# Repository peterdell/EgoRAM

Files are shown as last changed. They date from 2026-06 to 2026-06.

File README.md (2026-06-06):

# EgoRAM

The Atari 8-bit RAM cartridge with an own ego and opinion what should be in the RAM.

$D500-$D5FF
===========

| Address | Name | Descriptio Read | Write |
|---------+------+------------|
| $D500   |      | 'E'        |
| $D501   |      | 'R'        |
| $D502   |      | 'A'        |
| $D503   |      | 'M'        |
| $D504   |      | $YY        |
| $D505   |      | $YY        |
| $D506   |      | $MM        |
| $D507   |      | $DD        |

| $D508   |  ECTL  | $00=ready, $01=busy, $8x=error  | $00=reset,$01=begin command |
| $D509   |  EDAT  | Data, increments address        | Data to write, increments address |
| $dD0a   |  ERET  | n/a                             | Strobe, run command |

| Command | Name     | Arguments | Description 
| G       | Graphics | mode: byte (8,9,15), address: word ($8000...$bffff), width: byte (bytes 32,40,48), height: byte (lines 1..255) | width*height<$2000
| SD      | Shape Define | shapeNumber: word ($0001-$ffff), bpp: ($01, $02, $04), width: word (pixels 1..256), height: word (pixels 1..256), format: byte ($01=raw), paletteSize: word, paletteMap: array[paletteSize], maskIndex: byte (0..paletteSize), data: array[0...dataSize-1] | dataSize =

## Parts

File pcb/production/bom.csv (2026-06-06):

Designator | Footprint | Quantity | Value | LCSC Part #
J1 | PinHeader_1x04_P2.54mm_Horizontal | 1 | Conn_01x04_Pin
J7, J8 | PinSocket_1x20_P2.54mm_Vertical | 2 | Conn_01x20
SW1 | SW_PUSH_6mm_H8mm | 1 | SW_Push
U1, U3, U4, U5 | DIP-20_W7.62mm_Socket_LongPads | 4 | 74LS245
U2 | Atari8Cartridge MountHoles (taller) | 1 | Atari8Cartridge
U6 | DIP-14_W7.62mm_LongPads | 1 | 74LS08

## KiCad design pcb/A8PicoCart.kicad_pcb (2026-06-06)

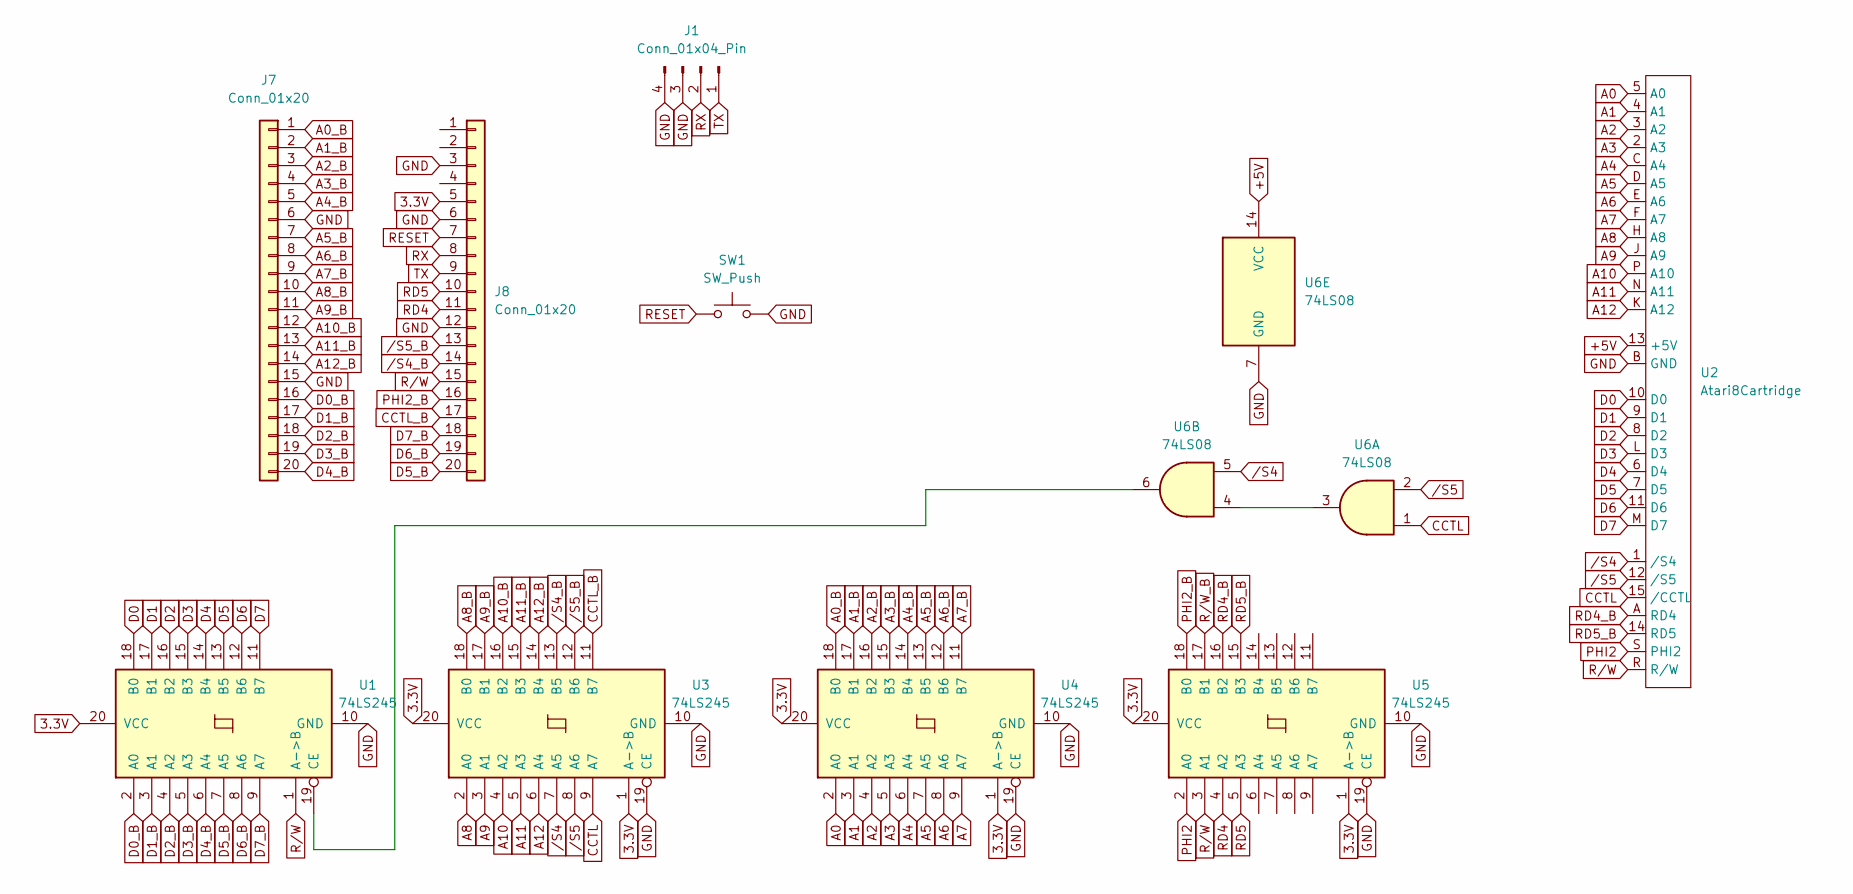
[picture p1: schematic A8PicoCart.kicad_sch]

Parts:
J1: Conn_01x04_Pin; PinHeader_1x04_P2.54mm_Horizontal
J7, J8: Conn_01x20; PinSocket_1x20_P2.54mm_Vertical
SW1: SW_Push; SW_PUSH_6mm_H8mm
U1, U3, U4, U5: 74LS245; DIP-20_W7.62mm_Socket_LongPads
U2: Atari8Cartridge; Atari8Cartridge MountHoles (taller)
U6: 74LS08; DIP-14_W7.62mm_LongPads

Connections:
3.3V: J8.5, U1.20 (VCC), U3.1 (A->B), U3.20 (VCC), U4.1 (A->B), U4.20 (VCC), U5.1 (A->B), U5.20 (VCC)
+5V: U2.13 (+5V), U6.14 (VCC)
A0: U2.5 (A0), U4.2 (A0)
A0_B: J7.1, U4.18 (B0)
A1: U2.4 (A1), U4.3 (A1)
A1_B: J7.2, U4.17 (B1)
A2: U2.3 (A2), U4.4 (A2)
A2_B: J7.3, U4.16 (B2)
A3: U2.2 (A3), U4.5 (A3)
A3_B: J7.4, U4.15 (B3)
A4: U2.C (A4), U4.6 (A4)
A4_B: J7.5, U4.14 (B4)
A5: U2.D (A5), U4.7 (A5)
A5_B: J7.7, U4.13 (B5)
A6: U2.E (A6), U4.8 (A6)
A6_B: J7.8, U4.12 (B6)
A7: U2.F (A7), U4.9 (A7)
A7_B: J7.9, U4.11 (B7)
A8: U2.H (A8), U3.2 (A0)
A8_B: J7.10, U3.18 (B0)
A9: U2.J (A9), U3.3 (A1)
A9_B: J7.11, U3.17 (B1)
A10: U2.P (A10), U3.4 (A2)
A10_B: J7.12, U3.16 (B2)
A11: U2.N (A11), U3.5 (A3)
A11_B: J7.13, U3.15 (B3)
A12: U2.K (A12), U3.6 (A4)
A12_B: J7.14, U3.14 (B4)
CCTL: U2.15 (/CCTL), U3.9 (A7), U6.1
CCTL_B: J8.17, U3.11 (B7)
D0: U1.18 (B0), U2.10 (D0)
D0_B: J7.16, U1.2 (A0)
D1: U1.17 (B1), U2.9 (D1)
D1_B: J7.17, U1.3 (A1)
D2: U1.16 (B2), U2.8 (D2)
D2_B: J7.18, U1.4 (A2)
D3: U1.15 (B3), U2.L (D3)
D3_B: J7.19, U1.5 (A3)
D4: U1.14 (B4), U2.6 (D4)
D4_B: J7.20, U1.6 (A4)
D5: U1.13 (B5), U2.7 (D5)
D5_B: J8.20, U1.7 (A5)
D6: U1.12 (B6), U2.11 (D6)
D6_B: J8.19, U1.8 (A6)
D7: U1.11 (B7), U2.M (D7)
D7_B: J8.18, U1.9 (A7)
GND: J1.3, J1.4, J7.6, J7.15, J8.3, J8.6, J8.12, SW1.2, U1.10 (GND), U2.B (GND), U3.10 (GND), U3.19 (CE), U4.10 (GND), U4.19 (CE), U5.10 (GND), U5.19 (CE), U6.7 (GND)
unnamed: U1.19 (CE), U6.6
unnamed: U6.3, U6.4
PHI2: U2.S (PHI2), U5.2 (A0)
PHI2_B: J8.16, U5.18 (B0)
RD4: J8.11, U5.4 (A2)
RD4_B: U2.A (RD4), U5.16 (B2)
RD5: J8.10, U5.5 (A3)
RD5_B: U2.14 (RD5), U5.15 (B3)
RESET: J8.7, SW1.1
RX: J1.2, J8.8
R/W: J8.15, U1.1 (A->B), U2.R (R/W), U5.3 (A1)
R/W_B: U5.17 (B1)
TX: J1.1, J8.9
/S4: U2.1 (/S4), U3.7 (A5), U6.5
/S4_B: J8.14, U3.13 (B5)
/S5: U2.12 (/S5), U3.8 (A6), U6.2
/S5_B: J8.13, U3.12 (B6)

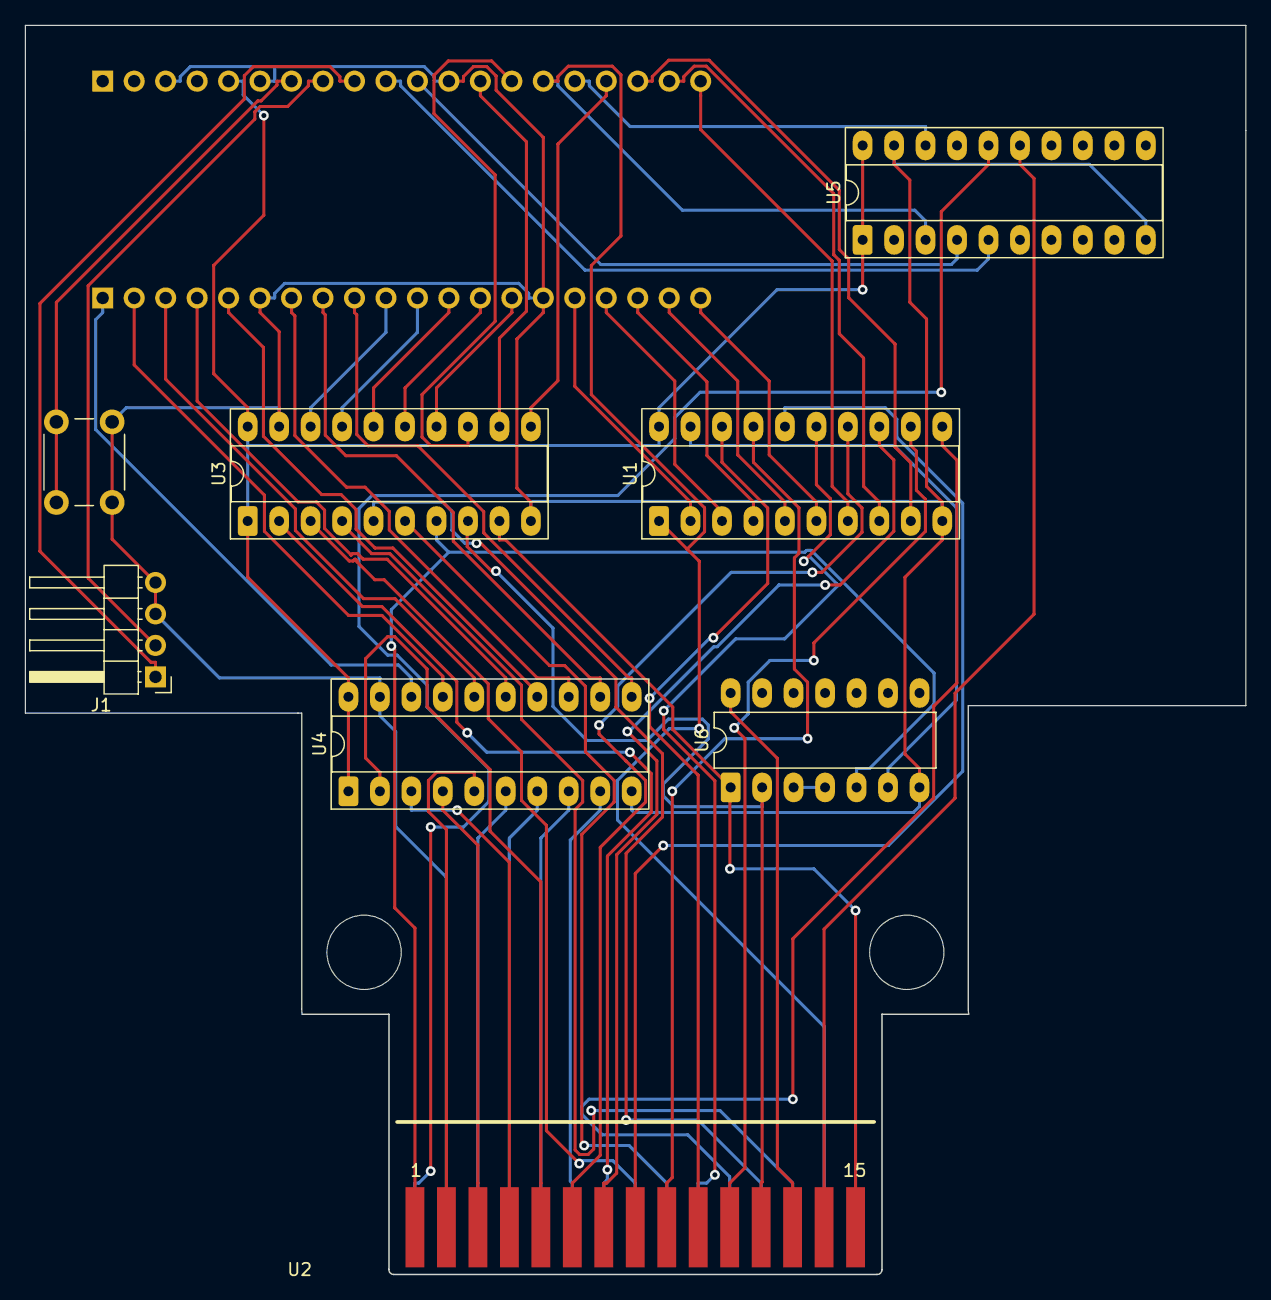
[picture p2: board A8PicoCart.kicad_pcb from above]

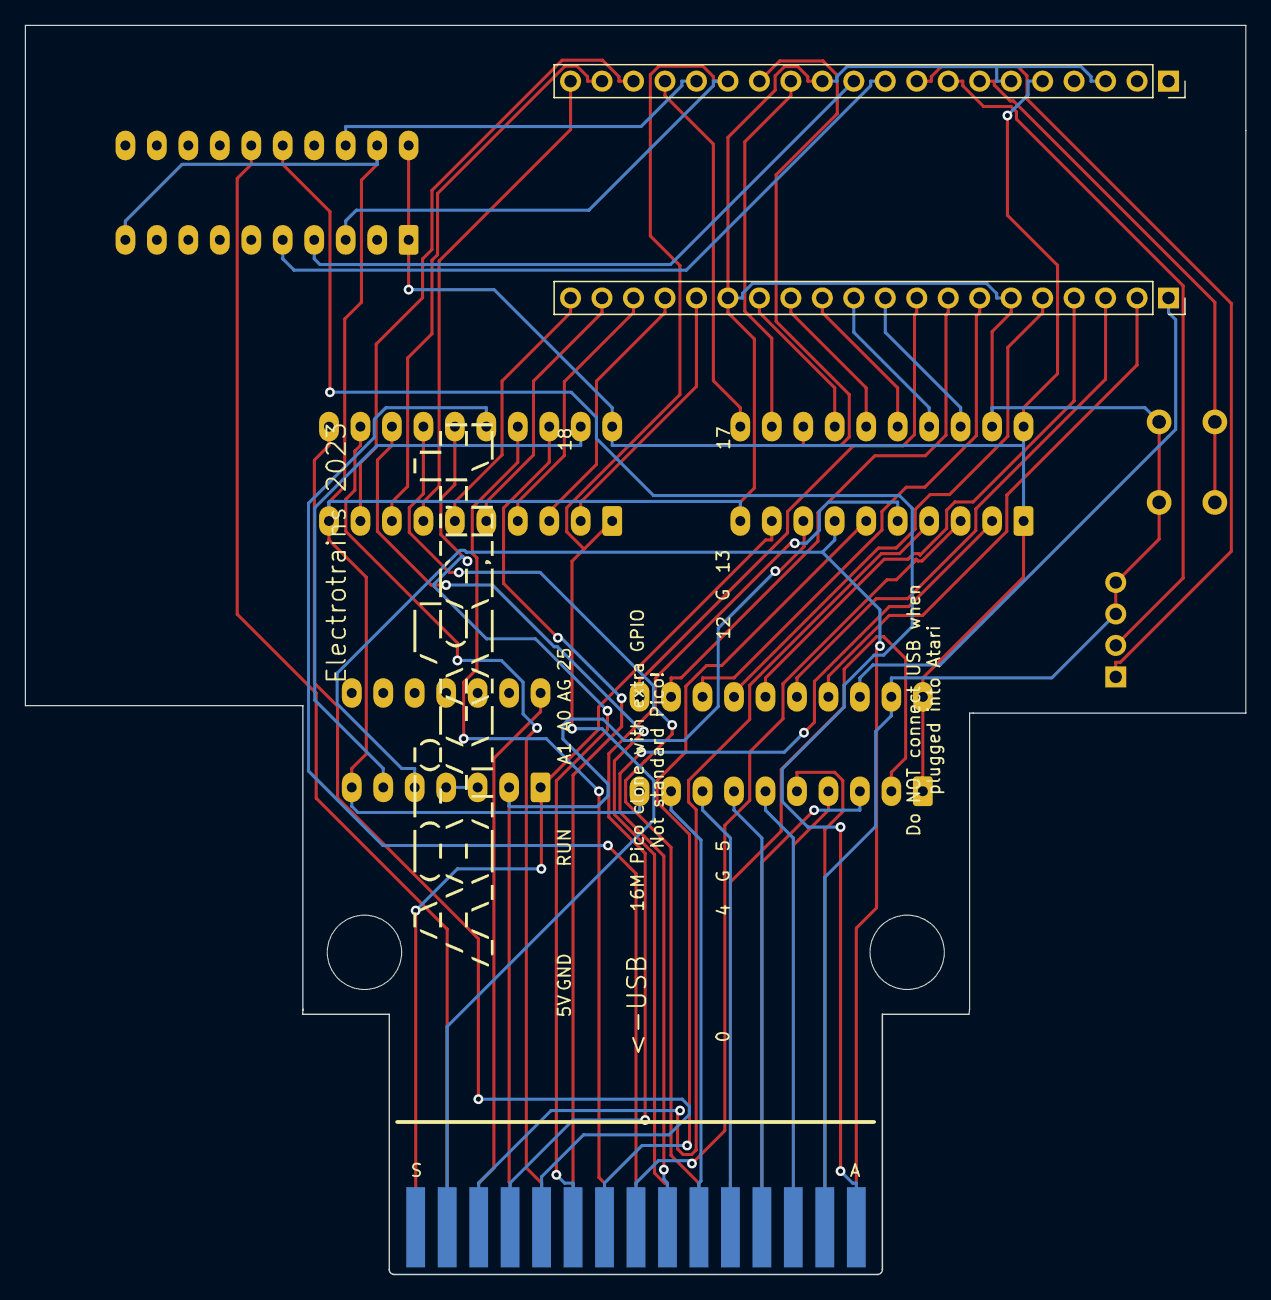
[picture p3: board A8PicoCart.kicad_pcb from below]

Board: 2 copper layers, 98.5 x 100.8 mm, 10 parts (2 on the bottom side), 63 nets.

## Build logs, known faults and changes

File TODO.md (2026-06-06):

- Create Atari test/sample program

- Define D500 Layout
- Implement BUSY Bit

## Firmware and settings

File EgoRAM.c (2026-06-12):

/**
 * Copyright (c) 2020 Raspberry Pi (Trading) Ltd.
 *
 * SPDX-License-Identifier: BSD-3-Clause
 */

/*

A0-12  13
D0-7    8
CCTL    1   gpio 21
PHI2    1   gpio 22
RW      1   gpio 23
S4      1   gpio 24
S5      1   gpio 25
    ------
       26
    ======

#define ALL_GPIO_MASK 0x3FFFFFFF
#define ADDR_GPIO_MASK 0x00001FFF
#define DATA_GPIO_MASK 0x001FE000
#define CCTL_GPIO_MASK 0x00200000 // gpio 21
#define PHI2_GPIO_MASK 0x00400000 // gpio 22
#define RW_GPIO_MASK 0x00800000	  // gpio 23
#define S4_GPIO_MASK 0x01000000	  // gpio 24
#define S5_GPIO_MASK 0x02000000	  // gpio 25
*/

#include <stdio.h>
#include <stdlib.h>
#include <string.h>
#include <stdarg.h>
#include "pico/stdlib.h"
#include "pico/multicore.h"
#include "pico/rand.h"
#include "hardware/pio.h"
#include "hardware/clocks.h"
#include "hardware/pll.h"
#include "hardware/structs/systick.h"
#include "hardware/vreg.h"
#include "hardware/structs/bus_ctrl.h"
#include "hardware/regs/busctrl.h"

#include "vt100_font_8x8.h"
#include "atari_cart.h"
#include "EgoRAM.h"
#include "cvideo.h"

char c;

int dx_array[EGO_MAX_SPRITES];
int dy_array[EGO_MAX_SPRITES];

static char strbuf[80];

static uint8_t *char_font = (uint8_t *)vt100_font_8x8;
static uint32_t mode;

static volatile uint8_t *video_ram;
static volatile uint8_t *cart_d5xx;
static volatile uint32_t ticks;
static bool uart_init_once;

static uint8_t ego_cmd;
static uint32_t ego_state;
static uint32_t ego_shape_no;
static uint32_t ego_sprite_no;
static uint32_t ego_line_no;
static uint32_t ego_line_cnt;
static uint32_t ego_shape_width;
static uint32_t ego_shape_height;
static uint16_t ego_blitwidth;
static uint16_t ego_blitheight;
static uint16_t ego_line_ptr[256];

static shape_t shape_array[EGO_MAX_SHAPES];
static sprite_t sprite_array[EGO_MAX_SPRITES];

static PIO pio = pio0;

static void systick_init(void)
{
    systick_hw->csr = 0x5;        // Enable + CPU-Clock als Quelle
    systick_hw->rvr = 0x00FFFFFF; // Maximaler Reload-Wert (24-Bit)
}

uint16_t __not_in_flash_func(get_blitwidth)()
{
    return ego_blitwidth;
}

void __not_in_flash_func(set_blitwidth)(uint16_t width)
{
    ego_blitwidth = width;
}

uint16_t __not_in_flash_func(get_blitheight)()
{
    return ego_blitheight;
}

void __not_in_flash_func(set_blitheight)(uint16_t height)
{
    ego_blitheight = height;
}

uint8_t __not_in_flash_func(read_vram)(uint16_t addr)
{
    return video_ram[addr];
}

void __not_in_flash_func(write_vram)(uint16_t addr, uint8_t data)
{
    if (addr >= 0x1fff)
    {
        ego_log("error vram addr: %d\n", addr);
    }
    else
    {
        video_ram[addr] = data;
    }
}

void __not_in_flash_func(sprite_draw)(sprite_t *sp)
{

    int xpos = sp->xpos;
    int ypos = sp->ypos;
    int width = shape_array[sp->shape_no].width;
    int height = shape_array[sp->shape_no].height;

    int pixx = xpos & 0x07;
    int bytex = (xpos >> 3);

    int ystart;
    int vstart;
    int ylen;
    int vdiff;
    int x, y;

    uint16_t vpos;
    uint8_t *sppos;
    uint8_t b, c;

    // ego_log("blitwidth: %d, blitheight %d\n", ego_blitwidth, ego_blitheight);
    // ego_log("sprite_draw: shape_no:%d, x:%d y:%d, width:%d, height: %d \n", sp->shape_no, xpos, ypos, width, height);

    /*
    for (y = 0; y < height; y++)
    {
        for (x = 0; x < width; x++)
        {
            ego_log("%02X ", shape_array[sp->shape_no].data[y * width + x]);
        }
        ego_log("\n");
    }
    */

    // if (xpos < 0 || ypos < 0)
    //    return;

    ystart = height - ypos;
    if (ystart < 0)
        ystart = 0;

    ylen = height - ystart;

    vstart = ypos - height;
    if (vstart < 0)
        vstart = 0;

    vdiff = ego_blitheight + height - ypos;
    if (vdiff < height)
    {
        ylen = vdiff;
    }

    sppos = &(shape_array[sp->shape_no].data[ystart * width]);

    // ego_log("sprite xpos:%d ypos:%d bytex: %d pixx:%d ystart:%d ylen:%d vstart:%d \n", xpos, ypos, bytex, pixx, ystart, ylen, vstart);

    for (y = 0; y < ylen; y++)
    {
        c = 0;

        // vpos = &video_ram[ego_line_ptr[vstart + y]];
        vpos = ego_line_ptr[vstart + y] + bytex;

        if (vstart + y >= 192)
            ego_log("vstart too high %d\n", vstart + y);

        for (x = 0; x < width; x++)
        {
            if (bytex + x >= 0 && bytex + x < ego_blitwidth)
            {
                b = read_vram(vpos + x);
                b ^= (c | (sppos[x] >> pixx));
                write_vram(vpos + x, b);
            }
            // vpos[bytex + x] ^= (c | (sppos[x] >> pixx));
            c = (sppos[x]) << (8 - pixx);
        }

        if (bytex + x >= 0 && bytex + x < ego_blitwidth)
        {
            // vpos = &video_ram[ego_line_ptr[vstart + y]];
            // vpos[bytex + x] ^= c;
            vpos = ego_line_ptr[vstart + y] + bytex;
            b = read_vram(vpos + x);
            b ^= c;
            write_vram(vpos + x, b);
        }

        sppos += width;
    }
}

void __not_in_flash_func(render_sprites)(void)
{

    sprite_t *sp;

    for (int i = 0; i < EGO_MAX_SPRITES; i++)
    {
        sp = &sprite_array[i];

        if (sp->enabled)
        {
            sprite_draw(sp);
        }
    }
}

void do_movement()
{
    sprite_t *sp;
    uint16_t xpos, ypos;

    for (int i = 0; i < EGO_MAX_SPRITES; i++)
    {
        sp = &sprite_array[i];

        if (sp->enabled)
        {
            sprite_draw(sp);

            xpos = sp->xpos;
            ypos = sp->ypos;

            xpos += dx_array[i];
            if (xpos >= (ego_blitwidth - shape_array[sp->shape_no].width) << 3 || xpos <= 0)
            {
                dx_array[i] *= -1;
                xpos += dx_array[i];
            }

            ypos += dy_array[i];
            if (ypos >= ego_blitheight || ypos - shape_array[sp->shape_no].height <= 0)
            {
                dy_array[i] *= -1;
                ypos += dy_array[i];
            }

            sp->xpos = xpos;
            sp->ypos = ypos;

            sprite_draw(sp);
        }
    }

    cart_d5xx[EGO_REG_STATUS] &= ~0x80;
}

void __not_in_flash_func(do_data)(uint8_t data)
{
    switch (ego_state)
    {
    case EGO_ST_SHAPE_NO:
        ego_shape_no = data;
        ego_state = EGO_ST_SHAPE_WIDTH;
        break;
    case EGO_ST_SHAPE_WIDTH:
        shape_array[ego_shape_no].width = data;
        ego_state = EGO_ST_SHAPE_HEIGHT;
        break;
    case EGO_ST_SHAPE_HEIGHT:
        shape_array[ego_shape_no].height = data;
        if (shape_array[ego_shape_no].data != NULL)
        {
            free(shape_array[ego_shape_no].data);
        }
        shape_array[ego_shape_no].data = malloc(shape_array[ego_shape_no].width * shape_array[ego_shape_no].height);
        shape_array[ego_shape_no].count = 0;

        ego_state = EGO_ST_SHAPE_DATA;
        break;
    case EGO_ST_SHAPE_DATA:
        shape_array[ego_shape_no].data[shape_array[ego_shape_no].count] = data;
        shape_array[ego_shape_no].count++;

        if (shape_array[ego_shape_no].count == shape_array[ego_shape_no].width * shape_array[ego_shape_no].height)
        {
            ego_state = EGO_ST_IDLE;
        }
        break;
    case EGO_ST_SPRITE_NO:
        ego_sprite_no = data;

        if (ego_cmd == EGO_CMD_SET_SPRITE_X || ego_cmd == EGO_CMD_SET_SPRITE_XY)
            ego_state = EGO_ST_SPRITE_X_LO;
        else if (ego_cmd == EGO_CMD_SET_SPRITE_Y)
            ego_state = EGO_ST_SPRITE_Y_LO;
        else
            ego_state = EGO_ST_SPRITE_SHAPE_NO;
        break;
    case EGO_ST_SPRITE_SHAPE_NO:
        sprite_array[ego_sprite_no].shape_no = data;
        ego_state = EGO_ST_IDLE;
        break;
    case EGO_ST_SPRITE_X_LO:
        sprite_array[ego_sprite_no].xold = sprite_array[ego_sprite_no].xpos;
        sprite_array[ego_sprite_no].xpos = data;
        ego_state = EGO_ST_SPRITE_X_HI;
        break;
    case EGO_ST_SPRITE_X_HI:
        sprite_array[ego_sprite_no].xpos |= data << 8;
        if (ego_cmd == EGO_CMD_SET_SPRITE_XY)
            ego_state = EGO_ST_SPRITE_Y_LO;
        else
            ego_state = EGO_ST_IDLE;
        break;
    case EGO_ST_SPRITE_Y_LO:
        sprite_array[ego_sprite_no].yold = sprite_array[ego_sprite_no].ypos;
        sprite_array[ego_sprite_no].ypos = data;
        ego_state = EGO_ST_SPRITE_Y_HI;
        break;
    case EGO_ST_SPRITE_Y_HI:
        sprite_array[ego_sprite_no].ypos |= data << 8;
        ego_state = EGO_ST_IDLE;
        break;
    case EGO_ST_SPRITE_ENA:
        ego_sprite_no = data;
        sprite_array[ego_sprite_no].enabled = true;
        ego_state = EGO_ST_IDLE;
        break;
    case EGO_ST_SPRITE_DIS:
        ego_sprite_no = data;
        sprite_array[ego_sprite_no].enabled = false;
        ego_state = EGO_ST_IDLE;
        break;
    case EGO_ST_BLITWITH:
        ego_blitwidth = data;
        ego_state = EGO_ST_IDLE;
        break;
    case EGO_ST_BLITHEIGHT:
        ego_blitheight = data;
        ego_state = EGO_ST_IDLE;
        break;
    case EGO_ST_LINE_NO:
        ego_line_no = data;
        ego_line_cnt = 0;
        ego_state = EGO_ST_LINE_DATA_LO;
        break;
    case EGO_ST_LINE_DATA_LO:
        ego_line_ptr[ego_line_cnt] = data;
        ego_state = EGO_ST_LINE_DATA_HI;
        break;
    case EGO_ST_LINE_DATA_HI:
        ego_line_ptr[ego_line_cnt++] |= (data & 0x1f) << 8;
        if (ego_line_cnt >= ego_line_no)
        {
            ego_state = EGO_ST_IDLE;
            ego_log("cnt:%d %04X\n", ego_line_cnt, ego_line_ptr[ego_line_cnt - 1]);
        }
        else
            ego_state = EGO_ST_LINE_DATA_LO;
        break;
    default:
        break;
    }
}

void __not_in_flash_func(do_command)(uint8_t data)
{
    ego_cmd = data;

    switch (ego_cmd)
    {
    case EGO_CMD_RENDER_SPRITES:
        render_sprites();
        break;
    case EGO_CMD_SET_WRITEABLE:
        set_writeable(true);
        cart_d5xx[EGO_REG_STATUS] |= 0x01;
        break;
    case EGO_CMD_SET_READONLY:
        set_writeable(false);
        cart_d5xx[EGO_REG_STATUS] &= ~0x01;
        break;
    case EGO_CMD_ABORT:
        ego_state = EGO_ST_IDLE;
        break;
    case EGO_CMD_SHAPE_DATA:
        ego_state = EGO_ST_SHAPE_NO;
        break;
    case EGO_CMD_DEL_SHAPE:
        break;
    case EGO_CMD_SPRITE_DATA:
        ego_state = EGO_ST_SPRITE_NO;
        break;
    case EGO_CMD_DEL_SPRITE:
        break;
    case EGO_CMD_ENA_SPRITE:
        ego_state = EGO_ST_SPRITE_ENA;
        break;
    case EGO_CMD_DIS_SPRITE:
        ego_state = EGO_ST_SPRITE_DIS;
        break;
    case EGO_CMD_SET_SPRITE_X:
        ego_state = EGO_ST_SPRITE_NO;
        break;
    case EGO_CMD_SET_SPRITE_Y:
        ego_state = EGO_ST_SPRITE_NO;
        break;
    case EGO_CMD_SET_SPRITE_XY:
        ego_state = EGO_ST_SPRITE_NO;
        break;
    case EGO_CMD_SET_BLIT_WIDTH:
        ego_state = EGO_ST_BLITWITH;
        break;
    case EGO_CMD_SET_BLIT_HEIGHT:
        ego_state = EGO_ST_BLITHEIGHT;
        break;
    case EGO_CMD_LINE_PTR:
        ego_state = EGO_ST_LINE_NO;
        break;
    case EGO_CMD_MOVEMENT:
        do_movement();
        break;
    default:
        break;
    }
}

void __not_in_flash_func(core1_main)()
{
    uint32_t msg;
    uint32_t data;
    uint32_t addr;

    systick_init();

    ego_log("core1 started...\n");

    while (true)
    {
        msg = multicore_fifo_pop_blocking();

        ticks = systick_hw->cvr;

        addr = msg & 0xff;
        data = msg >> 16;

        switch (addr)
        {
        case EGO_REG_CMD:
            do_command(data);
            /*
            if (data == EGO_CMD_RENDER_SPRITES)
            {
                ticks = (ticks - systick_hw->cvr) & 0xffffff;
                ego_log("addr: %04X, data: %02X, ticks: %d\n", msg & 0xffff, msg >> 16, ticks);
            }
            */
            break;
        case EGO_REG_DATA:
            do_data(data);
            break;
        default:
            break;
        }

        cart_d5xx[EGO_REG_STATUS] &= ~0x80;
    }
}

void __not_in_flash_func(putChar)(int xpos, int ypos, uint8_t c)
{
    // ego_log("%p %02X ", (ypos * ego_blitwidth * 8) + xpos, c);

    uint8_t volatile *pscreen = &video_ram[(ypos * ego_blitwidth * 8) + xpos];
    uint8_t *pchar = &char_font[c << 3];

    for (int i = 0; i < 8; i++)
    {
        *pscreen = *pchar;
        pchar++;
        pscreen += ego_blitwidth;
    }
}

uint8_t read_d5xx(uint8_t addr)
{
    return cart_d5xx[addr];
}

void __not_in_flash_func(write_d5xx)(uint8_t addr, uint8_t data)
{

    cart_d5xx[EGO_REG_STATUS] |= 0x80;

    if (multicore_fifo_wready)
    {
        multicore_fifo_push_blocking(addr | (data << 16));
    }
    else 
    {
        ego_log("write to FiFo failed\n");
    }
}

void __not_in_flash_func(ego_log)(const char *format, ...)
{

    va_list args;

    va_start(args, format);
    vsnprintf(strbuf, sizeof(strbuf), format, args);
    va_end(args);

    if (mode == EGO_MODE_USB)
    {
        while (!stdio_usb_connected())
        {
            sleep_ms(100);
        }

        printf("%s", strbuf);
    }
    else
    {
        if (!uart_init_once)
        {
            uart_init_once = true;
            uart_init(EGO_UART_ID, EGO_BAUD_RATE);
            gpio_set_function(EGO_UART_TX_PIN, GPIO_FUNC_UART);
            gpio_set_function(EGO_UART_RX_PIN, GPIO_FUNC_UART);
        }

        uart_puts(EGO_UART_ID, strbuf);
    }
}

void test()
{
    int width = 40;
    int height = 200;
    int x, y, c;
    uint16_t ptr = 0;

    write_d5xx(EGO_REG_CMD, EGO_CMD_SET_BLIT_WIDTH);
    write_d5xx(EGO_REG_DATA, (uint8_t)width);
    write_d5xx(EGO_REG_CMD, EGO_CMD_SET_BLIT_HEIGHT);
    write_d5xx(EGO_REG_DATA, (uint8_t)height);

    write_d5xx(EGO_REG_CMD, EGO_CMD_LINE_PTR);
    write_d5xx(EGO_REG_DATA, 200);
    for (x = 0; x < 200; x++)
    {
        write_d5xx(EGO_REG_DATA, ptr & 0xff);
        write_d5xx(EGO_REG_DATA, ptr >> 8);
        ptr += width;
    }

    for (x = 0; x < EGO_MAX_SPRITES; x++)
    {
        dx_array[x] = 1;
        if (get_rand_32() & 0x01)
            dx_array[x] *= -1;

        dy_array[x] = 1;
        if (get_rand_32() & 0x01)
            dy_array[x] *= -1;
    }

    c = 0;
    for (y = 0; y < (height >> 3); y++)
    {
        for (x = 0; x < width; x++)
        {
            putChar(x, y, c);
            c++;
        }
    }

    write_d5xx(EGO_REG_CMD, EGO_CMD_SHAPE_DATA);
    write_d5xx(EGO_REG_DATA, 0x00); // shape number
    write_d5xx(EGO_REG_DATA, 0x01); // shape width
    write_d5xx(EGO_REG_DATA, 0x08); // shape height
    write_d5xx(EGO_REG_DATA, 0xff); // shape data
    write_d5xx(EGO_REG_DATA, 0xff); // shape data
    write_d5xx(EGO_REG_DATA, 0xff); // shape data
    write_d5xx(EGO_REG_DATA, 0xff); // shape data
    write_d5xx(EGO_REG_DATA, 0xff); // shape data
    write_d5xx(EGO_REG_DATA, 0xff); // shape data
    write_d5xx(EGO_REG_DATA, 0xff); // shape data
    write_d5xx(EGO_REG_DATA, 0xff); // shape data

    for (int i = 0; i < EGO_MAX_SPRITES; i++)
    {
        write_d5xx(EGO_REG_CMD, EGO_CMD_SPRITE_DATA);
        write_d5xx(EGO_REG_DATA, i);    // sprite number
        write_d5xx(EGO_REG_DATA, 0x00); // shape number

        write_d5xx(EGO_REG_CMD, EGO_CMD_SET_SPRITE_XY);
        write_d5xx(EGO_REG_DATA, i);                            // sprite number
        write_d5xx(EGO_REG_DATA, get_rand_32() % (width << 3)); // sprite X lo
        write_d5xx(EGO_REG_DATA, 0x00);                         // sprite X hi
        write_d5xx(EGO_REG_DATA, get_rand_32() % height);       // sprite Y lo
        write_d5xx(EGO_REG_DATA, 0x00);                         // sprite Y hi

        write_d5xx(EGO_REG_CMD, EGO_CMD_ENA_SPRITE);
        write_d5xx(EGO_REG_DATA, i); // sprite number
    }

    write_d5xx(EGO_REG_CMD, EGO_CMD_RENDER_SPRITES);

    while (true)
    {
        c = getchar();
        printf("%c", c);

        /*
        write_d5xx(EGO_REG_CMD, EGO_CMD_RENDER_SPRITES);
        while (read_d5xx(EGO_REG_STATUS) & 0x80)
            ;

        sprite_array[0].xpos++;
        sprite_array[0].ypos++;

        write_d5xx(EGO_REG_CMD, EGO_CMD_RENDER_SPRITES);
        while (read_d5xx(EGO_REG_STATUS) & 0x80)
            ;
        */
    }
}

void set_core0_highest_bus_priority()
{
    // Setzt die Bus-Priorität für Kern 0 auf hoch (1) und Kern 1 auf niedrig (0)
    bus_ctrl_hw->priority = BUSCTRL_BUS_PRIORITY_PROC0_BITS;
}

int main()
{
    vreg_set_voltage(VREG_VOLTAGE_1_20);
    sleep_ms(100);
    set_sys_clock_khz(250000, true);
    sleep_ms(100);
    systick_init();

    stdio_init_all();

    // check to see if we are plugged into Atari 8-bit
    // by checking for high on PHI2 gpio for xxx ms
    gpio_init(ATARI_PHI2_PIN);
    gpio_set_dir(ATARI_PHI2_PIN, GPIO_IN);

    uart_init_once = false;
    mode = EGO_MODE_USB;

    while (to_ms_since_boot(get_absolute_time()) < 300)
    {
        if (gpio_get(ATARI_PHI2_PIN))
        {
            mode = EGO_MODE_ATARI;
        }
    }

    video_ram = get_cart_ram();
    cart_d5xx = get_cart_d5xx();

    memset((void *)video_ram, 0x01, 4 * 1024);
    memset((void *)video_ram + 0x1000, 0x10, 4 * 1024);
    memset((void *)video_ram + 0x2000, 0xaa, 8 * 1024);
    memset((void *)sprite_array, 0x00, sizeof(sprite_array));
    memset((void *)shape_array, 0x00, sizeof(shape_array));

    ego_log("\033[2J\033[HEgoRAM starting...\n");
    if (mode == EGO_MODE_USB)
        ego_log("mode: USB\n");
    else
        ego_log("mode: ATARI\n");

    ego_log("sys_clock: %d\n", clock_get_hz(clk_sys));
    ego_log("video_ram at %p\n", video_ram);
    ego_log("cart_d5xx at %p\n", cart_d5xx);

    for (int x = 0; x < EGO_MAX_SPRITES; x++)
    {
        dx_array[x] = 1;
        if (get_rand_32() & 0x01)
            dx_array[x] *= -1;

        dy_array[x] = 1;
        if (get_rand_32() & 0x01)
            dy_array[x] *= -1;
    }

    multicore_launch_core1(core1_main);

    if (mode == EGO_MODE_ATARI)
    {
        // irq_set_enabled(USBCTRL_IRQ, false);
        uint32_t status = save_and_disable_interrupts();
        set_core0_highest_bus_priority();
        atari_cart_main();
    }

    initialise_cvideo(pio0);

    test();
}

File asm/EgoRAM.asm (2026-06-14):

ptr			= 0

COLBK			= $D01A

DLIST			= $D402
VCOUNT			= $D40B
NMIEN			= $D40E

EGO_REG_CMD		= $D500
EGO_REG_STATUS		= $D501
EGO_REG_DATA		= $D502

EGO_CMD_RENDER_SPRITES	= 0
EGO_CMD_SET_WRITEABLE	= 1
EGO_CMD_SET_READONLY	= 2
EGO_CMD_ABORT		= 3
EGO_CMD_SHAPE_DATA	= 4
EGO_CMD_DEL_SHAPE	= 5
EGO_CMD_SPRITE_DATA	= 6
EGO_CMD_DEL_SPRITE	= 7
EGO_CMD_ENA_SPRITE	= 8
EGO_CMD_DIS_SPRITE	= 9
EGO_CMD_SET_SPRITE_X	= 10
EGO_CMD_SET_SPRITE_Y	= 11
EGO_CMD_SET_SPRITE_XY	= 12
EGO_CMD_SET_BLIT_WIDTH	= 13
EGO_CMD_SET_BLIT_HEIGHT	= 14
EGO_CMD_LINE_PTR	= 15
EGO_CMD_MOVEMENT 	= 99

width			= 40
widthpix		= width * 8
height			= 192
MAXSPRITES		= 32

RANDOM			= $D20A

	org $2000

cnt	= $14

;sm	= $a010
sm	= $8010
sm_width = 40
screen_lines = 192
lines_4k=102
size_4k=sm_width*lines_4k
	
	.proc main

	mwa #dl $230	
	mva #14 708
	mva #08 709
	mva #00 710
	
	
	ldx cnt
	inx
	inx

waitvbi	cpx cnt
	bne waitvbi 

	lda #<sm
	sta ptr
	lda #>sm
	sta ptr+1
	
	lda #EGO_CMD_ABORT
	sta EGO_REG_CMD
	
	ldx #192
	lda #EGO_CMD_LINE_PTR
	sta EGO_REG_CMD
	stx EGO_REG_DATA
	
lineptr	lda ptr
	sta EGO_REG_DATA
	lda ptr+1
	sta EGO_REG_DATA
	
	clc
	lda ptr
	adc #40
	sta ptr
	lda ptr+1
	adc #0
	sta ptr+1
	
	dex
	bne lineptr
	
	mva #EGO_CMD_SET_BLIT_WIDTH	EGO_REG_CMD
	mva #width			EGO_REG_DATA
	mva #EGO_CMD_SET_BLIT_HEIGHT	EGO_REG_CMD
	mva #height			EGO_REG_DATA

;
; prepare shape
;	
	mva #EGO_CMD_SHAPE_DATA		EGO_REG_CMD
	mva #$00			EGO_REG_DATA		;shape no
	mva #3				EGO_REG_DATA		;shape x bytes
	mva #21				EGO_REG_DATA		;shape y lines
	
	ldx #3*21
	lda #$ff
shape0	sta EGO_REG_DATA
	dex
	bne shape0

;
; init X/Y pos and increments
;
	ldx #0
	ldy #0
	
randx:	lda RANDOM
	cmp #8
	bcc randx
	sta xpos,x
	lda #0
	sta xpos+1,x
	lda RANDOM
	and #1
	bne randxhi
	lda #$ff
	sta xinc,x
	sta xinc+1,x
	bne randy
	
randxhi	sta xinc,x
	lda #0
	sta xinc+1,x
	
randy:	lda RANDOM
	cmp #height
	bcs randy
	sta ypos,x
	lda #0
	sta ypos+1,x
	lda RANDOM
	and #1
	bne randyhi
	lda #$ff
	sta yinc,x
	sta yinc+1,x
	bne spriteshape
randyhi	sta yinc,x
	lda #0
	sta yinc+1,x

;
; associate sprite with shape
; enable sprite
;
spriteshape
	lda #EGO_CMD_SPRITE_DATA
	sta EGO_REG_CMD
	sty EGO_REG_DATA				; sprite no
        lda #$00					; shape number			
	sta EGO_REG_DATA	

	lda #EGO_CMD_SET_SPRITE_XY
	sta EGO_REG_CMD
	sty EGO_REG_DATA				; sprite no	
	lda xpos,x
	sta EGO_REG_DATA
	lda xpos+1,x
	sta EGO_REG_DATA
	lda ypos,x
	sta EGO_REG_DATA
	lda ypos+1,x
	sta EGO_REG_DATA
		
        lda #EGO_CMD_ENA_SPRITE
	sta EGO_REG_CMD
        sty EGO_REG_DATA				;sprite number				

	clc
	txa
	adc #8
	tax
	
	iny
	cpy #MAXSPRITES
	beq render
	jmp randx

;
;
;
render	lda #EGO_CMD_RENDER_SPRITES
	jsr sendcmd

	lda #0
	sta NMIEN
loop
	
waitvcnt2
	lda VCOUNT
	cmp #112
;	cmp #20
	bcc waitvcnt2

waitvcnt
;	lda VCOUNT
;	cmp #8
;	bcc waitvcnt

	lda #$02
	sta COLBK

	lda #EGO_CMD_RENDER_SPRITES
	jsr sendcmd

	lda #$04
	sta COLBK
	jsr domove
	
	lda #$06
	sta COLBK	
	jsr checkmove

	lda #$08
	sta COLBK	
	jsr setxy

	lda #10
	sta COLBK
	lda #EGO_CMD_RENDER_SPRITES
	jsr sendcmd

	lda #$00
	sta COLBK

waitvcnt1
	lda VCOUNT
;	cmp #2
	bmi waitvcnt1

	jmp loop

;
;
;
setxy	ldx #0
	ldy #0
	
setxy1	lda #EGO_CMD_SET_SPRITE_XY
	sta EGO_REG_CMD
	sty EGO_REG_DATA
	lda xpos,x
	sta EGO_REG_DATA
	lda xpos+1,x
	sta EGO_REG_DATA
	lda ypos,x
	sta EGO_REG_DATA
	lda ypos+1,x
	sta EGO_REG_DATA

	clc
	txa
	adc #8
	tax
	
	iny
	cpy #MAXSPRITES
	bne setxy1
	
	rts
	
;
;
;
checkmove
	ldx #0
	ldy #0
	
checkmove1
	lda xpos,x
	cmp #<widthpix
	lda xpos+1,x
	sbc #>widthpix
	bcc checkmovey
	
	lda #0
	sbc xinc,x
	sta xinc,x
	lda #0
	sbc xinc+1,x
	sta xinc+1,x
	
	

checkmovey
	
	lda ypos,x
	cmp #<height
	lda ypos+1,x
	sbc #>height
	bcc checkmove2
	
	lda #0
	sbc yinc,x
	sta yinc,x
	lda #0
	sbc yinc+1,x
	sta yinc+1,x

;	jsr addinc	

checkmove2	
	clc
	txa
	adc #8
	tax
	
	iny
	cpy #MAXSPRITES
	bne checkmove1
	
checkmoveex
	rts
	

;
;
;	
domove	ldx #0
	ldy #MAXSPRITES
	
domove1	jsr addinc
	inx
	inx
	inx
	inx
	jsr addinc
	inx
	inx
	inx
	inx
	
	dey
	bne domove1
	rts	

;
;
;
addinc	clc
	lda xpos,x
	adc xinc,x
	sta xpos,x	
	lda xpos+1,x
	adc xinc+1,x
	sta xpos+1,x
	rts
	

sendcmd	sta EGO_REG_CMD
sendcw	lda EGO_REG_STATUS
	bmi sendcw
	rts

senddat	sta EGO_REG_DATA
senddw	bit EGO_REG_STATUS
	bmi senddw
	rts

xpos	.word 0
xinc	.word 0
ypos	.word 0
yinc	.word 0

	.endp
	
	.align $400
	.local dl
	dc =$0f

	.byte $70,$70,$70
	.byte $40+dc,a(sm)
:101	.byte dc
	.byte $40+dc,a(sm+size_4k)
:89	.byte dc
	.byte $41,a(dl)
	.endl
	
	
	run main

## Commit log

2026-06-06 refactoring & busy bit
    [A8PicoCart.kicad_pcb, A8PicoCart.kicad_sch, bom.csv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]
2026-06-12 write to d5xx fixed
    [EgoRAM.c, atari_cart.c]
